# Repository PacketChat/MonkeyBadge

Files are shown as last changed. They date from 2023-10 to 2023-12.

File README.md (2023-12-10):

# Monkey Badge

This repository contains the hardware design files, badge code, and backend
infrastructure code for the HushCon Winter 2023 badge.

## badge

The code for the badge is based on [Micropython][1].  For full documentation
read the datasheet, comments, and commit history.

## api-server

The api-server is the backend gameserver it provides an API
interface for the badge to save state and complete challenges.

You will need a redis server with the json mod, `docker run -d -p 6379:6379
redislabs/redismod` works fine.

This is based on FastAPI and is easily executed with: `cd api-server; python3
api-server`

## scoreboard

Built, with Flask

<!--
vim: ts=2 sw=2 tw=80 syntax=md
!-->

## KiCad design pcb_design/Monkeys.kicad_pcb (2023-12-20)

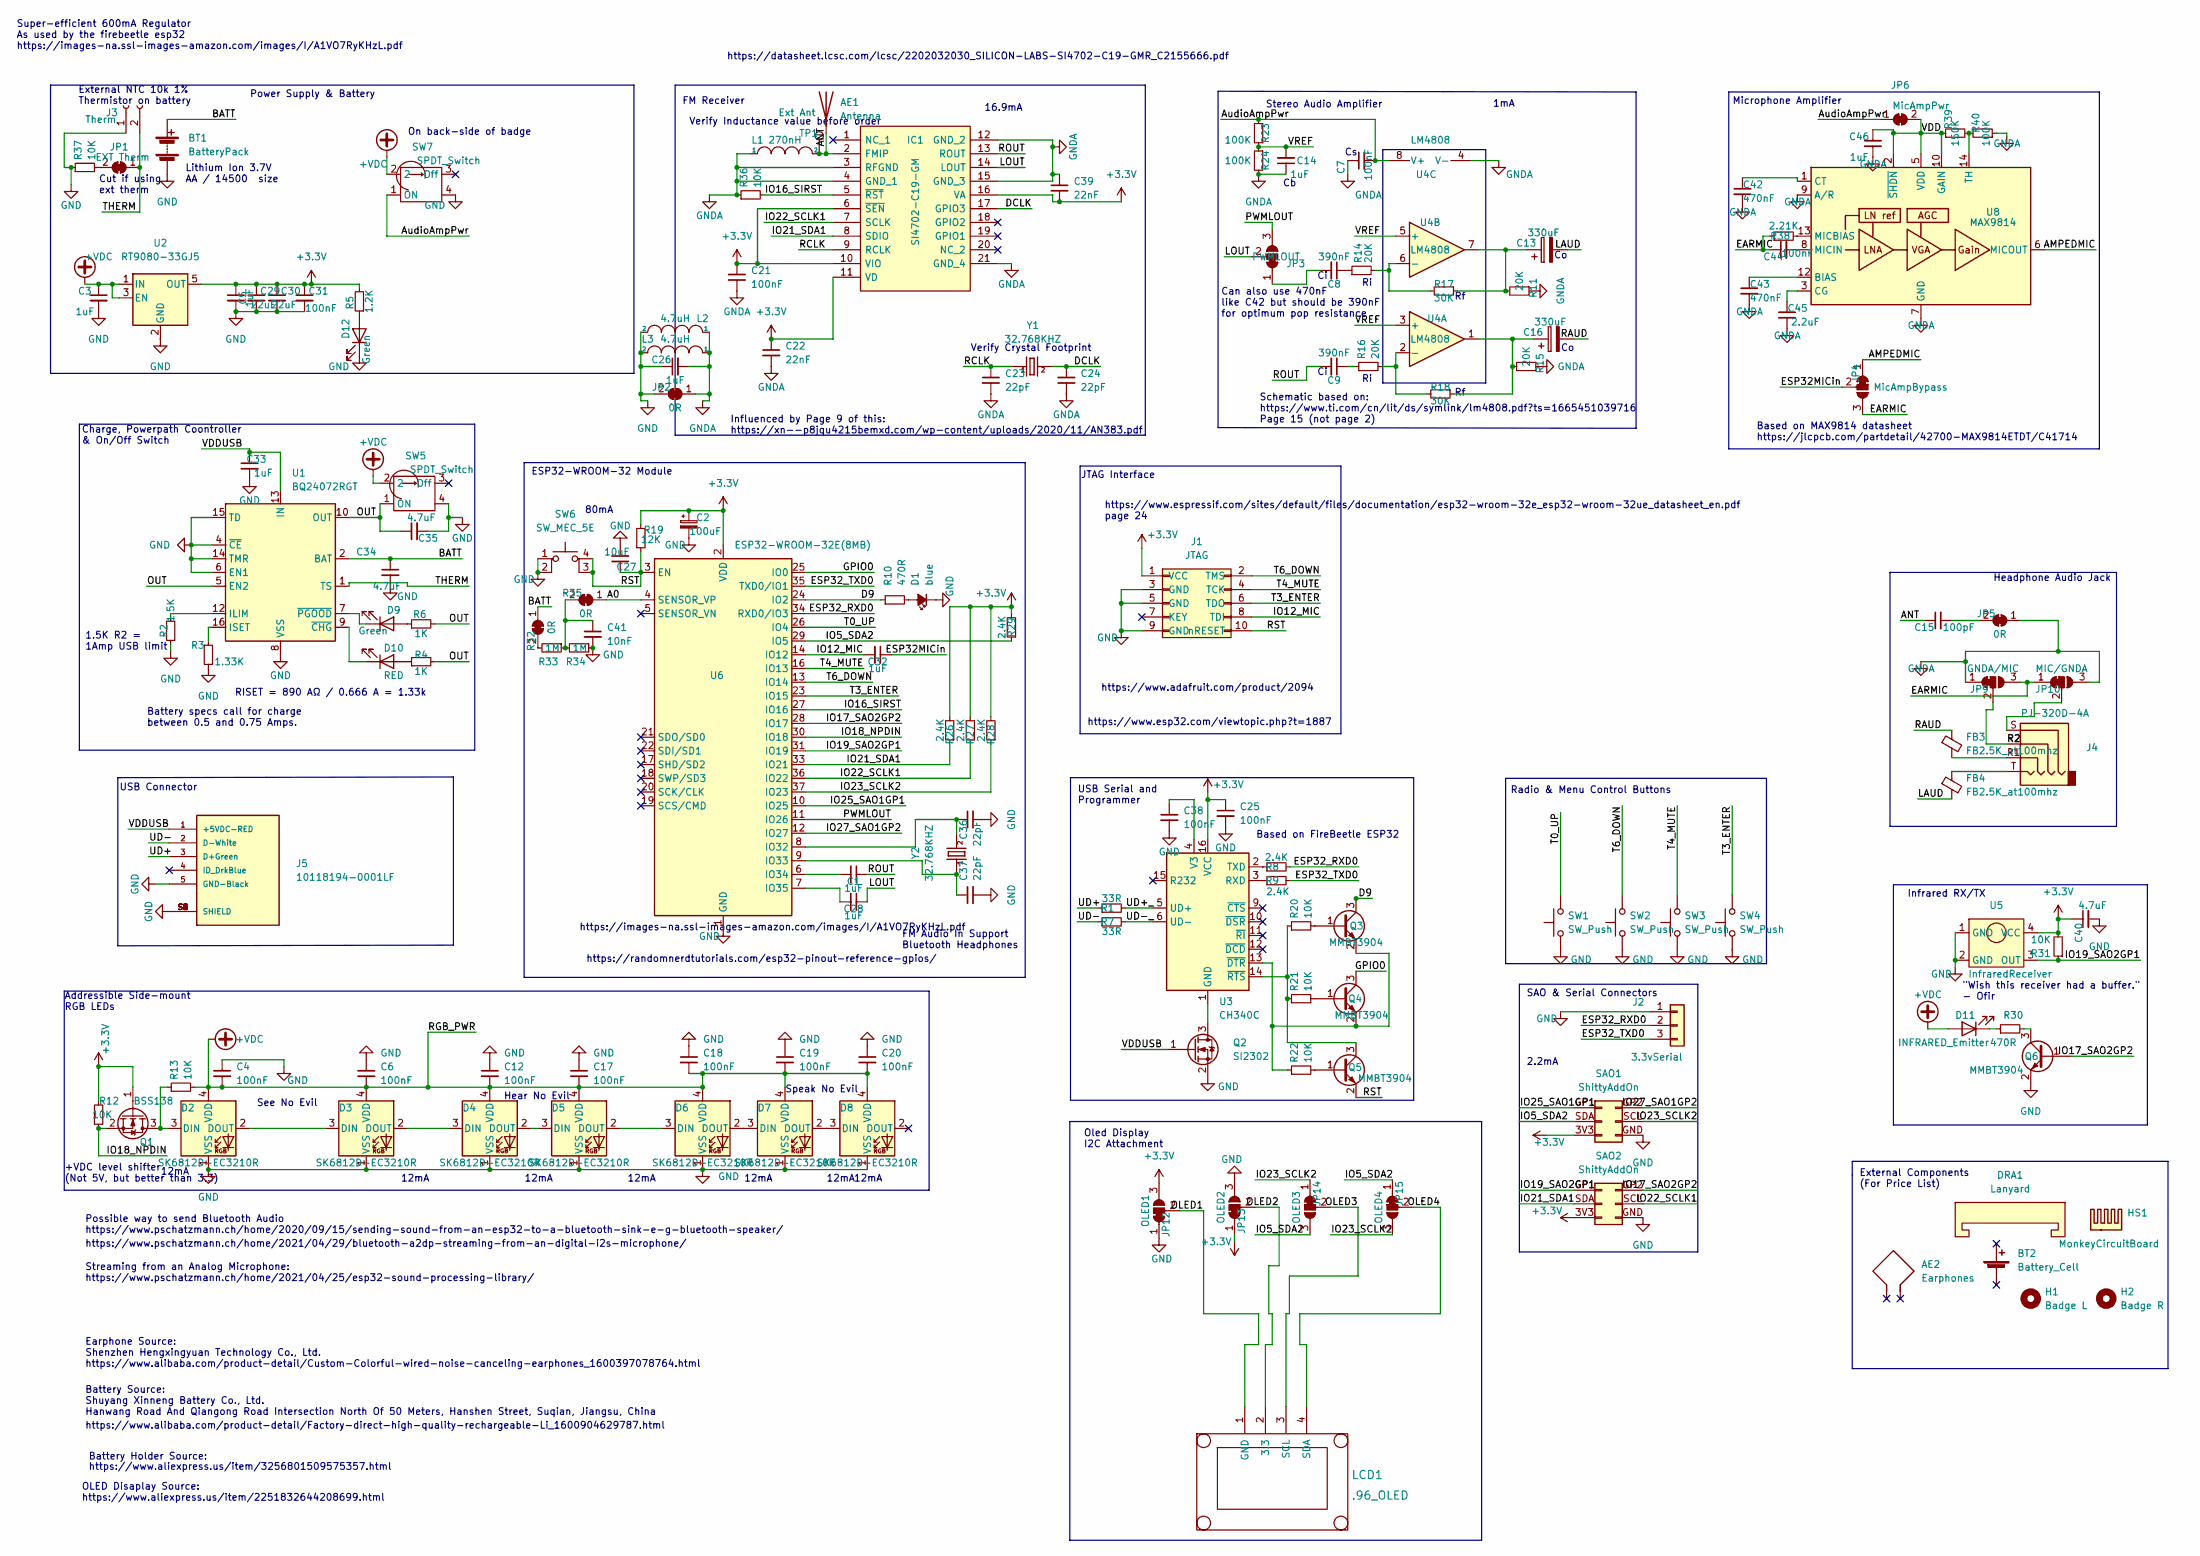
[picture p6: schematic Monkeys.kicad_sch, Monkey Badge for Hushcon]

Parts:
AE1: Antenna; Manufacturer_Part_Number DNP; JLCPCB Part #（optional) DNP
AE2: Earphones; Manufacturer_Part_Number DNP; JLCPCB Part #（optional) DNP
BT1: BatteryPack; 1xAA_NUB; Manufacturer_Part_Number DNP; JLCPCB Part #（optional) DNP
BT2: Battery_Cell; Manufacturer_Part_Number DNP; JLCPCB Part #（optional) DNP
C1, C3, C5, C14, C26, C28, C32, C46: 1uF; C_0402_1005Metric; Manufacturer_Part_Number CC0402KRX5R6BB105; JLCPCB Part #（optional) C106254
C2: 100uF; CP_EIA-6032-20_AVX-F; Manufacturer_Part_Number TAJC107K010RNJ; JLCPCB Part #（optional) C8649
C4, C6, C7, C12, C17, C18, C19, C20, C21, C25, C31, C38, C44: 100nF; C_0402_1005Metric; Manufacturer_Part_Number CL05B104KB54PNC; JLCPCB Part #（optional) C307331
C8, C9: 390nF; C_0402_1005Metric; Manufacturer_Part_Number GRM155R61A394KE15D; JLCPCB Part #（optional) C350937
C13, C16: 330uF; CP_EIA-7343-31_Kemet-D; Manufacturer_Part_Number 6TPC330MA; JLCPCB Part #（optional) C558795
C15: 100pF; C_0402_1005Metric; Manufacturer_Part_Number 0402CG101J500NT; JLCPCB Part #（optional) C1546
C22, C39: 22nF; C_0402_1005Metric; Manufacturer_Part_Number 0402B223K500NT; JLCPCB Part #（optional) C1532
C23, C24, C36, C37: 22pF; C_0402_1005Metric; Manufacturer_Part_Number 0402CG220J500NT; JLCPCB Part #（optional) C1555
C27: 10uF; C_0603_1608Metric; Manufacturer_Part_Number CL10A106KP8NNNC; JLCPCB Part #（optional) C19702
C29, C30: 22uF; C_0805_2012Metric; Manufacturer_Part_Number CL21A226MAQNNNE; JLCPCB Part #（optional) C45783
C33: 1uF; C_0805_2012Metric; Manufacturer_Part_Number CC0805KKX7R8BB105; JLCPCB Part #（optional) C91186
C34, C35, C40: 4.7uF; C_0603_1608Metric; Manufacturer_Part_Number CC0603KRX5R6BB475; JLCPCB Part #（optional) C109456
C41: 10nF; C_0402_1005Metric; Manufacturer_Part_Number CL05B103KB5NNNC; JLCPCB Part #（optional) C15195
C42, C43: 470nF; C_0402_1005Metric; Manufacturer_Part_Number C1005X5R474KDTS; JLCPCB Part #（optional) C147712
C45: 2.2uF; C_0402_1005Metric; Manufacturer_Part_Number LMK105ABJ225MVHF; JLCPCB Part #（optional) C386041
D1: blue; LED_0402_1005Metric; Manufacturer_Part_Number TJ-S1005SW4TGLC6B-A5; JLCPCB Part #（optional) C273603
D2, D3, D4, D5, D6, D7, D8: SK6812D-EC3210R; Manufacturer_Part_Number SK6812D-EC3210R; JLCPCB Part #（optional) C2890041
D9, D12: Green; LED_0805_2012Metric; Manufacturer_Part_Number 17-215SYGC/S530-E2/TR8; JLCPCB Part #（optional) C282125
D10: RED; LED_0603_1608Metric; Manufacturer_Part_Number KT-0603R; JLCPCB Part #（optional) C2286
D11: INFRARED_Emitter; LED_1206_3216Metric; Manufacturer_Part_Number MHT153IRCT; JLCPCB Part #（optional) C2764887
DRA1: Lanyard; DNP; Manufacturer_Part_Number DNP; JLCPCB Part #（optional) DNP
FB3, FB4: FB2.5K_at100mhz; C_0603_1608Metric; Manufacturer_Part_Number SZ1608K252CTF; JLCPCB Part #（optional) C316340
H1: Badge L; MountingHole_4.5mm; Manufacturer_Part_Number DNP; JLCPCB Part #（optional) DNP
H2: Badge R; MountingHole_4.5mm; Manufacturer_Part_Number DNP; JLCPCB Part #（optional) DNP
HS1: MonkeyCircuitBoard; DNP; Manufacturer_Part_Number DNP; JLCPCB Part #（optional) DNP
IC1: SI4702-C19-GM; SI4702C19GM; Manufacturer_Part_Number SI4702-C19-GM; JLCPCB Part #（optional) C2155666
J1: JTAG; PinHeader_2x05_P1.27mm_Vertical; Manufacturer_Part_Number DNP; JLCPCB Part #（optional) DNP
J2: 3.3vSerial; PinSocket_1x03_P2.54mm_Vertical; Manufacturer_Part_Number DNP; JLCPCB Part #（optional) DNP
J3: Therm; PinHeader_1x02_P2.54mm_Vertical; Manufacturer_Part_Number DNP; JLCPCB Part #（optional) DNP
J4: PJ-320D-4A; Jack_3.5mm_PJ320D_Horizontal; Manufacturer_Part_Number PJ-320D-4A; JLCPCB Part #（optional) C95562
J5: 10118194-0001LF; AMPHENOL_10118194-0001LF_JT; Manufacturer_Part_Number 10118194-0001LF; JLCPCB Part #（optional) C132563
JP1: EXT Therm; SolderJumper-2_P1.3mm_Bridged_RoundedPad1.0x1.5mm; Manufacturer_Part_Number DNP; JLCPCB Part #（optional) DNP
JP2, JP5: 0R; SolderJumper-2_P1.3mm_Bridged_RoundedPad1.0x1.5mm; Manufacturer_Part_Number DNP; JLCPCB Part #（optional) DNP
JP3: PWMLOUT; SolderJumper-3_P1.3mm_Bridged12_RoundedPad1.0x1.5mm; Manufacturer_Part_Number DNP; JLCPCB Part #（optional) DNP
JP4: MicAmpBypass; SolderJumper-3_P1.3mm_Bridged12_RoundedPad1.0x1.5mm; Manufacturer_Part_Number DNP; JLCPCB Part #（optional) DNP
JP6: MicAmpPwr; SolderJumper-2_P1.3mm_Bridged_RoundedPad1.0x1.5mm
JP9: GNDA/MIC; SolderJumper-3_P1.3mm_Bridged12_RoundedPad1.0x1.5mm; Manufacturer_Part_Number DNP; JLCPCB Part #（optional) DNP
JP10: MIC/GNDA; SolderJumper-3_P1.3mm_Bridged12_RoundedPad1.0x1.5mm; Manufacturer_Part_Number DNP; JLCPCB Part #（optional) DNP
JP12: OLED1; SolderJumper-3_P1.3mm_Bridged12_RoundedPad1.0x1.5mm; Manufacturer_Part_Number DNP; JLCPCB Part #（optional) DNP
JP13: OLED2; SolderJumper-3_P1.3mm_Bridged12_RoundedPad1.0x1.5mm; Manufacturer_Part_Number DNP; JLCPCB Part #（optional) DNP
JP14: OLED3; SolderJumper-3_P1.3mm_Bridged12_RoundedPad1.0x1.5mm; Manufacturer_Part_Number DNP; JLCPCB Part #（optional) DNP
JP15: OLED4; SolderJumper-3_P1.3mm_Bridged12_RoundedPad1.0x1.5mm; Manufacturer_Part_Number DNP; JLCPCB Part #（optional) DNP
L1: 270nH; L_0603_1608Metric_Pad1.05x0.95mm_HandSolder; Manufacturer_Part_Number SCHF160808HR27JT; JLCPCB Part #（optional) C578010
L2, L3: 4.7uH; L_0603_1608Metric_Pad1.05x0.95mm_HandSolder; Manufacturer_Part_Number MLP2012S4R7MT0S1; JLCPCB Part #（optional) C87543
LCD1: .96_OLED; PinHeader_1x04_P2.54mm_Vertical; Manufacturer_Part_Number DNP; JLCPCB Part #（optional) DNP
Q1: BSS138; SOT-323_SC-70; Manufacturer_Part_Number BSS138W-7-F; JLCPCB Part #（optional) C24553
Q2: SI2302; SOT-23; Manufacturer_Part_Number SI2302; JLCPCB Part #（optional) C351399
Q3, Q4, Q5, Q6: MMBT3904; SOT-23; Manufacturer_Part_Number MMBT3904; JLCPCB Part #（optional) C20526
R1, R7: 33R; R_0402_1005Metric; Manufacturer_Part_Number 0402WGF330JTCE; JLCPCB Part #（optional) C25105
R2: 1.5K; R_0805_2012Metric; Manufacturer_Part_Number RC0805FR-071K5L; JLCPCB Part #（optional) C114555
R3: 1.33K; R_0603_1608Metric; Manufacturer_Part_Number RC0603FR-071K33L; JLCPCB Part #（optional) C137778
R4, R6: 1K; R_0805_2012Metric; Manufacturer_Part_Number RC0805JR-071KL; JLCPCB Part #（optional) C100046
R5: 1.2K; R_0805_2012Metric; Manufacturer_Part_Number AR05FTDW1201; JLCPCB Part #（optional) C724883
R8, R9, R26, R27, R28, R29: 2.4K; R_0603_1608Metric; Manufacturer_Part_Number RC0603FR-072K4L; JLCPCB Part #（optional) C114611
R10, R30: 470R; R_0402_1005Metric; Manufacturer_Part_Number 0402WGF4700TCE; JLCPCB Part #（optional) C25117
R11, R14, R15, R16: 20K; R_0402_1005Metric; Manufacturer_Part_Number 0402WGF2002TCE; JLCPCB Part #（optional) C25765
R12, R13, R20, R21, R22, R31, R36, R37: 10K; R_0402_1005Metric; Manufacturer_Part_Number RC0402FR-0710KL; JLCPCB Part #（optional) C60490
R17, R18: 30K; R_0402_1005Metric; Manufacturer_Part_Number RC0402FR-0730KL; JLCPCB Part #（optional) C138008
R19: 12K; R_0402_1005Metric; Manufacturer_Part_Number RC0402FR-0712KL; JLCPCB Part #（optional) C114760
R23, R24, R40: 100K; R_0402_1005Metric; Manufacturer_Part_Number 0402WGF1003TCE; JLCPCB Part #（optional) C25741
R32, R35: 0R; SolderJumper-2_P1.3mm_Bridged_RoundedPad1.0x1.5mm; Manufacturer_Part_Number DNP; JLCPCB Part #（optional) DNP
R33, R34: 1M; R_0402_1005Metric; Manufacturer_Part_Number 0402WGF1004TCE; JLCPCB Part #（optional) C26083
R38: 2.21K; R_0402_1005Metric; Manufacturer_Part_Number NQ02WGF2211TCE; JLCPCB Part #（optional) C270376
R39: 150K; R_0402_1005Metric; Manufacturer_Part_Number AF0402FR-07150KL; JLCPCB Part #（optional) C144033
SAO1, SAO2: ShittyAddOn; ShittyAddOn_Female; Manufacturer_Part_Number DNP; JLCPCB Part #（optional) DNP
SW1, SW2, SW3, SW4: SW_Push; SW_SPST_PTS645; Manufacturer_Part_Number TSA063G50-250; JLCPCB Part #（optional) C294565
SW5, SW7: SPDT_Switch; SPDT Switch MSK12C02-HB; Manufacturer_Part_Number MSK12C02-HB; JLCPCB Part #（optional) C431541
SW6: SW_MEC_5E; Button_metal; Manufacturer_Part_Number TS-1187A-B-A-B; JLCPCB Part #（optional) C318884
TP1: Ext Ant; PinHeader_1x01_P2.54mm_Vertical; Manufacturer_Part_Number DNP; JLCPCB Part #（optional) DNP
U1: BQ24072RGT; VQFN-16-1EP_3x3mm_P0.5mm_EP1.6x1.6mm; Manufacturer_Part_Number BQ24072RGTR; JLCPCB Part #（optional) C140288
U2: RT9080-33GJ5; SOT-23-5; Manufacturer_Part_Number RT9080-33GJ5; JLCPCB Part #（optional) C841192
U3: CH340C; SOIC-16_3.9x9.9mm_P1.27mm; Manufacturer_Part_Number CH340C; JLCPCB Part #（optional) C84681
U4: LM4808; SOIC-8_3.9x4.9mm_P1.27mm; Manufacturer_Part_Number LM4808MX/NOPB; JLCPCB Part #（optional) C141374
U5: InfraredReceiver; IRM-H638T-TR2; Manufacturer_Part_Number IRM-H638T/TR2(DX); JLCPCB Part #（optional) C390031
U6: ESP32-WROOM-32E(8MB); ESP32-WROOM-32; Manufacturer_Part_Number ESP32-WROOM-32E(8MB); JLCPCB Part #（optional) C701342
U8: MAX9814; DFN-14-1EP_3x3mm_P0.4mm_EP1.78x2.35mm; Manufacturer_Part_Number MAX9814ETD+T; JLCPCB Part #（optional) C41714
Y1, Y2: 32.768KHZ; Crystal_SMD_3215-2Pin_3.2x1.5mm; Manufacturer_Part_Number SF32WK32768D31T002; JLCPCB Part #（optional) C271654

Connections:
+3V3: C2.1, C5.1, C21.1, C22.1, C25.1, C29.1, C30.1, C31.1, C39.2, C40.1, IC1.6 (~SEN), IC1.10 (VIO), IC1.11 (VD), IC1.16 (VA), J1.1 (VCC), JP12.3 (B), JP13.1 (A), Q1.1 (G), R5.2, R12.2, R19.2, R26.2, R27.2, R28.2, R29.2, R31.2, SAO1.3V3, SAO2.3V3, U2.5 (OUT), U3.16 (VCC), U5.4 (VCC), U6.2 (VDD)
+VDC: C3.1, C4.2, C6.2, C12.2, C17.2, C18.2, C19.2, C20.2, D2.4 (VDD), D3.4 (VDD), D4.4 (VDD), D5.4 (VDD), D6.4 (VDD), D7.4 (VDD), D8.4 (VDD), D11.2 (A), R13.2, SW5.2, SW7.2, U2.1 (IN), U2.3 (EN)
/A0: R35.1 (A), U6.4 (SENSOR_VP)
/AMPEDMIC: JP4.1 (A), U8.6 (MICOUT)
/ANT: AE1.1, C15.1, IC1.2 (FMIP), L1.2, TP1.1
/AudioAmpPwr: C7.2, JP6.1 (A), R23.1, SW7.1 (ON), U4.8 (V+)
/BATT: BT1.1 (+), C34.1, R32.1 (A), U1.2 (BAT), U1.3 (BAT)
/D9: Q3.3 (C), R10.1, U6.24 (IO2)
/DCLK: C24.1, IC1.17 (GPIO3), Y1.2
/EARMIC: C44.1, JP4.3 (B), JP9.3 (B), JP10.1 (A), R38.1
/ESP32MICin: C32.1, JP4.2 (C)
/ESP32_RXD0: J2.2, R8.2, U6.34 (RXD0/IO3)
/ESP32_TXD0: J2.3, R9.2, U6.35 (TXD0/IO1)
/GPIO0: Q4.3 (C), U6.25 (IO0)
/IO5_SDA2: JP14.3 (B), JP15.1 (A), R29.1, SAO1.SDA, U6.29 (IO5)
/IO12_MIC: C32.2, J1.8 (TDI), U6.14 (IO12)
/IO16_SIRST: IC1.5 (~RST), R36.2, U6.27 (IO16)
/IO17_SAO2GP2: Q6.1 (B), SAO2.GP2 (GPIO2), U6.28 (IO17)
/IO18_NPDIN: Q1.2 (S), R12.1, U6.30 (IO18)
/IO19_SAO2GP1: R31.1, SAO2.GP1 (GPIO1), U5.3 (OUT), U6.31 (IO19)
/IO21_SDA1: IC1.8 (SDIO), R26.1, SAO2.SDA, U6.33 (IO21)
/IO22_SCLK1: IC1.7 (SCLK), R27.1, SAO2.SCL, U6.36 (IO22)
/IO23_SCLK2: JP14.1 (A), JP15.3 (B), R28.1, SAO1.SCL, U6.37 (IO23)
/IO25_SAO1GP1: SAO1.GP1 (GPIO1), U6.10 (IO25)
/IO27_SAO1GP2: SAO1.GP2 (GPIO2), U6.12 (IO27)
/LAUD: C13.2, FB4.2
/LOUT: C28.1, IC1.14 (LOUT), JP3.2 (C)
/OLED1: JP12.2 (C), LCD1.1 (GND)
/OLED2: JP13.2 (C), LCD1.2 (3.3)
/OLED3: JP14.2 (C), LCD1.3 (SCL)
/OLED4: JP15.2 (C), LCD1.4 (SDA)
/OUT: C35.1, R4.2, R6.2, SW5.1 (ON), U1.5 (EN2), U1.10 (OUT), U1.11 (OUT)
/PWMLOUT: JP3.3 (B), U6.11 (IO26)
/R2: J4.R2, JP9.2 (C)
/RAUD: C16.2, FB3.1
/RCLK: C23.1, IC1.9 (RCLK), Y1.1
/ROUT: C1.1, C9.2, IC1.13 (ROUT)
/RST: C27.1, J1.10 (nRESET), Q5.2 (E), R19.1, SW6.3 (K), SW6.4 (A), U6.3 (EN)
/T0_UP: SW1.2, U6.26 (IO4)
/T3_ENTER: J1.6 (TDO), SW4.2, U6.23 (IO15)
/T4_MUTE: J1.4 (TCK), SW3.2, U6.16 (IO13)
/T6_DOWN: J1.2 (TMS), SW2.2, U6.13 (IO14)
/THERM: J3.2, JP1.1 (A), U1.1 (TS)
/UD+: J5.3 (D+Green), R1.1
/UD+_: R1.2, U3.5 (UD+)
/UD-: J5.2 (D-White), R7.1
/UD-_: R7.2, U3.6 (UD-)
/VDD: C46.1, JP6.2 (B), R39.1, U8.2 (~SHDN), U8.5 (VDD), U8.10 (GAIN)
/VDDUSB: C33.1, J5.1 (+5VDC-RED), Q2.1 (G), U1.13 (IN)
/VREF: C14.2, R23.2, R24.1, U4.3 (+), U4.5 (+)
GND: BT1.2 (-), C2.2, C3.2, C4.1, C5.2, C6.1, C12.1, C17.1, C18.1, C19.1, C20.1, C25.2, C26.1, C27.2, C29.2, C30.2, C31.2, C33.2, C34.2, C35.2, C36.2, C37.2, C38.2, C40.2, C41.2, D1.1 (K), D2.1 (VSS), D3.1 (VSS), D4.1 (VSS), D5.1 (VSS), D6.1 (VSS), D7.1 (VSS), D8.1 (VSS), D12.1 (K), J1.3 (GND), J1.5 (GND), J1.9 (GND), J2.1, J3.1, J5.5 (GND-Black), J5.S1 (SHIELD), J5.S2 (SHIELD), J5.S3 (SHIELD), J5.S4 (SHIELD), J5.S5 (SHIELD), J5.S6 (SHIELD), JP2.2 (B), JP12.1 (A), JP13.3 (B), L2.2, L3.2, Q2.2 (S), Q6.2 (E), R2.1, R3.2, R34.1, R37.1, SAO1.GND, SAO2.GND, SW1.1, SW2.1, SW3.1, SW4.1, SW5.4, SW6.1, SW6.2, SW7.4, U1.4 (~CE), U1.6 (EN1), U1.8 (VSS), U1.14 (TMR), U1.15 (TD), U1.17 (VSS), U2.2 (GND), U5.1 (GND), U5.2 (GND), U6.1 (GND), U6.15 (GND), U6.38 (GND), U6.39 (GND)
GNDA: C7.1, C14.1, C21.2, C22.2, C23.2, C24.2, C26.2, C39.1, C42.2, C43.2, C45.2, C46.2, IC1.3 (RFGND), IC1.4 (GND_1), IC1.12 (GND_2), IC1.15 (GND_3), IC1.21 (GND_4), JP2.1 (A), JP5.1 (A), JP9.1 (A), JP10.3 (B), L1.1, L2.1, L3.1, R11.1, R15.1, R24.2, R36.1, R40.1, U4.4 (V-), U8.4 (GND), U8.7 (GND), U8.9 (A/R), U8.11 (GND), U8.15 (GND)
unnamed: C1.2, U6.6 (IO34)
unnamed: C8.1, R14.1
unnamed: C8.2, JP3.1 (A)
unnamed: C9.1, R16.1
unnamed: C13.1, R11.2, R17.1, U4.7
unnamed: C15.2, JP5.2 (B)
unnamed: C16.1, R15.2, R18.1, U4.1
unnamed: C28.2, U6.7 (IO35)
unnamed: C36.1, U6.8 (IO32), Y2.2
unnamed: C37.1, U6.9 (IO33), Y2.1
unnamed: C38.1, U3.4 (V3)
unnamed: C41.1, R33.1, R34.2, R35.2 (B)
unnamed: C42.1, U8.1 (CT)
unnamed: C43.1, U8.12 (BIAS)
unnamed: C44.2, U8.8 (MICIN)
unnamed: C45.1, U8.3 (CG)
unnamed: D1.2 (A), R10.2
unnamed: D2.2 (DOUT), D3.3 (DIN)
unnamed: D2.3 (DIN), Q1.3 (D), R13.1
unnamed: D3.2 (DOUT), D4.3 (DIN)
unnamed: D4.2 (DOUT), D5.3 (DIN)
unnamed: D5.2 (DOUT), D6.3 (DIN)
unnamed: D6.2 (DOUT), D7.3 (DIN)
unnamed: D7.2 (DOUT), D8.3 (DIN)
unnamed: D9.1 (K), U1.7 (~PGOOD)
unnamed: D9.2 (A), R6.1
unnamed: D10.1 (K), U1.9 (~CHG)
unnamed: D10.2 (A), R4.1
unnamed: D11.1 (K), R30.1
unnamed: D12.2 (A), R5.1
unnamed: FB3.2, J4.R1
unnamed: FB4.1, J4.T
unnamed: J4.S, JP10.2 (C)
unnamed: JP1.2 (B), R37.2
unnamed: Q2.3 (D), U3.1 (GND)
unnamed: Q3.1 (B), R20.2
unnamed: Q3.2 (E), Q4.2 (E), R22.1, U3.13 (~DTR)
unnamed: Q4.1 (B), R21.2
unnamed: Q5.1 (B), R22.2
unnamed: Q5.3 (C), R20.1, R21.1, U3.14 (~RTS)
unnamed: Q6.3 (C), R30.2
unnamed: R2.2, U1.12 (ILIM)
unnamed: R3.1, U1.16 (ISET)
unnamed: R8.1, U3.2 (TXD)
unnamed: R9.1, U3.3 (RXD)
unnamed: R14.2, R17.2, U4.6 (-)
unnamed: R16.2, R18.2, U4.2 (-)
unnamed: R32.2 (B), R33.2
unnamed: R38.2, U8.13 (MICBIAS)
unnamed: R39.2, R40.2, U8.14 (TH)

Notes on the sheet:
See No Evil
Can also use 470nF like C42 but should be 390nF for optimum pop resistance
https://www.alibaba.com/product-detail/Factory-direct-high-quality-rechargeable-Li_1600904629787.html
Addressible Side-mount RGB LEDs
Battery specs call for charge between 0.5 and 0.75 Amps.
https://www.aliexpress.us/item/3256801509575357.html
12mA
Speak No Evil
https://datasheet.lcsc.com/lcsc/2202032030_SILICON-LABS-SI4702-C19-GMR_C2155666.pdf
On back-side of badge
"Wish this receiver had a buffer." - Ofir
Radio & Menu Control Buttons
https://randomnerdtutorials.com/esp32-pinout-reference-gpios/
Verify Inductance value before order
https://www.esp32.com/viewtopic.php?t=1887
1.5K R2 = 1Amp USB limit
https://www.pschatzmann.ch/home/2021/04/29/bluetooth-a2dp-streaming-from-an-digital-i2s-microphone/
+VDC level shifter (Not 5V, but better than 3.3)
Streaming from an Analog Microphone: https://www.pschatzmann.ch/home/2021/04/25/esp32-sound-processing-library/
Earphone Source: Shenzhen Hengxingyuan Technology Co., Ltd. https://www.alibaba.com/product-detail/Custom-Colorful-wired-noise-canceling-earphones_1600397078764.html
Based on FireBeetle ESP32
https://www.espressif.com/sites/default/files/documentation/esp32-wroom-32e_esp32-wroom-32ue_datasheet_en.pdf page 24
Cut if using ext therm
https://www.adafruit.com/product/2094
Stereo Audio Amplifier
Oled Display I2C Attachment
OLED Disaplay Source: https://www.aliexpress.us/item/2251832644208699.html
External Components (For Price List)
Headphone Audio Jack
Battery Source: Shuyang Xinneng Battery Co., Ltd. Hanwang Road And Qiangong Road Intersection North Of 50 Meters, Hanshen Street, Suqian, Jiangsu, China
https://images-na.ssl-images-amazon.com/images/I/A1VO7RyKHzL.pdf
SAO & Serial Connectors
Based on MAX9814 datasheet https://jlcpcb.com/partdetail/42700-MAX9814ETDT/C41714
Battery Holder Source:
RISET = 890 AΩ / 0.666 A = 1.33k
FM Audio In Support Bluetooth Headphones
Power Supply & Battery
2.2mA
Possible way to send Bluetooth Audio https://www.pschatzmann.ch/home/2020/09/15/sending-sound-from-an-esp32-to-a-bluetooth-sink-e-g-bluetooth-speaker/
Infrared RX/TX

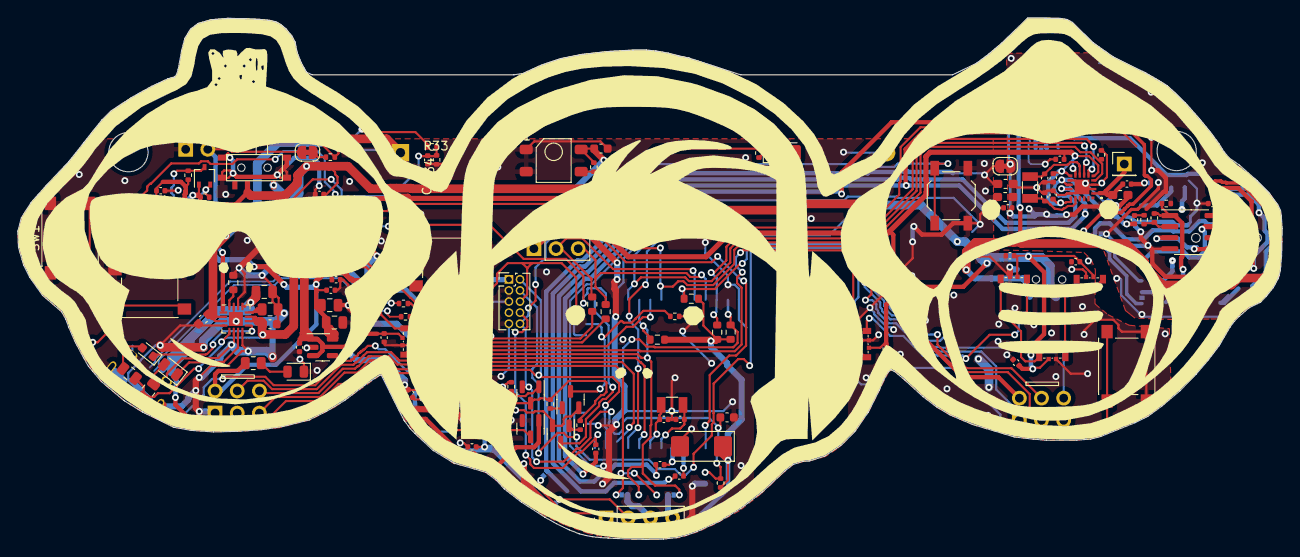
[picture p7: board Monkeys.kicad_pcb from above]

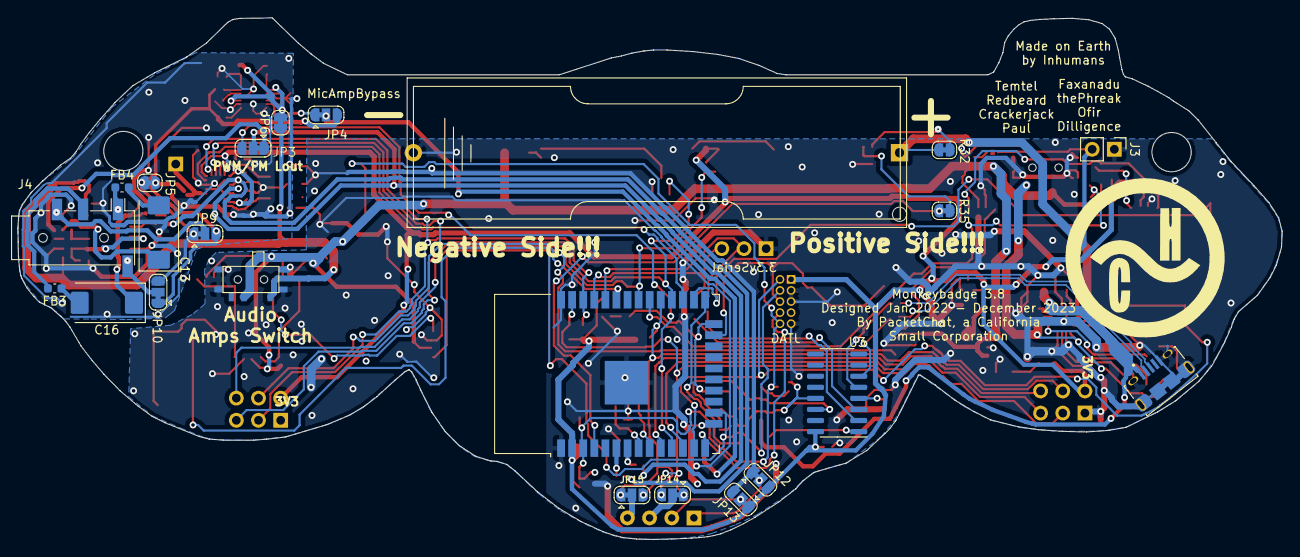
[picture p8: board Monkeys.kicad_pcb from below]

Board: 2 copper layers, 144.9 x 59.8 mm, 147 parts (23 on the bottom side), 102 nets.

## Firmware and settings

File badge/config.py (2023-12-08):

"""configuration settings"""
from collections import namedtuple
from esp32 import NVS

nvs = NVS("monkeybadge")
WIFI_SSID = "HushCon"
WIFI_PASSWORD = "ThreeAmigos"
API_SERVER = "https://update.kafka.tel/api"


def setNVS(key, value):
    nvs.set_blob(key, value)
    nvs.commit()


def getNVS(key, size):
    b = bytearray(size)
    nvs.get_blob(key, b)
    value = b.decode("utf-8").strip("\x00")
    del b
    return value


def eraseNVS(key):
    try:
        nvs.erase_key(key)
    except Exception:
        # TODO: if we don't mask this users will likely see they can modify the value "API_SERVER"
        # pass
        print("Unable to erase key {}".format(key))


# Wifi Config
try:
    WIFI_SSID = getNVS("WIFI_SSID", 32)
except Exception:
    pass

try:
    WIFI_PASSWORD = getNVS("WIFI_PASSWORD", 63)
except Exception:
    pass

try:
    API_SERVER = getNVS("API_SERVER", 255)
except Exception:
    pass

RESET_URL = "https://update.kafka.tel/firmware/reset.json"
UPDATE_URL = "https://update.kafka.tel/firmware/update.json"

# badge config
REG_KEY = "7bc78281-2036-41b2-8d98-fc23ec504e9a"
MONKEY_PERIOD = 5000
CHECKIN_PERIOD = 60000
BUTTON_PINS = [4, 14, 15, 13]
BUTTON_PIN_DESCRIPTIONS = [
    "left up",
    "left down",
    "center",
    "right",
]

# OLED screen Config
OLED_HEIGHT = 64  # height (int): Height of the display in pixels.
OLED_WIDTH = 128  # width (int): Width of the display in pixels.
OLED_SDA_PIN = 5  # sda_pin (int): Pin number for the SDA (data) line of the I2C bus.
OLED_SCL_PIN = 23  # scl_pin (int): Pin number for the SCL (clock) line of the I2C bus.

# IR Pins (also double as right SAO GPIO pins)
IR_RX_PIN = 19  # SAO2 GPIO1
IR_TX_PIN = 17  # SAO2 GPIO2

# SAO1 Pins
SAO1_GPIO1 = 25
SAO1_GPIO2 = 27


# IR Definitions Follow
# examples (addr, data):
# DISCOVER: (0x000a, 0x01)
# HERE: (0x000b, 0x02)  <--- add to last seen
# INIT_PAIR: (0x000a, 0x03)
# RESP_PAIR: (0x000b, 0x04, 0x00, 0x0a) <--- responding to 0x000a
# ACK_RESP: (0x000a, 0x05, 0x00, 0x0b) <--- confirming 0x000b response
# EMOTE: (0x000a, 0x06, 0x01, 0x00, 0x0b) <--- a wants be to show emote 0x01 (lol)
# EMOTE: (0x000b, 0x06, 0x02, 0xff, 0xff) <--- b wants all badges in the vicinity
#                                              to show emote 0x02 (lmao)
# MONKEY: (0xffff, 0x07, 0xaa, 0xaa) <--- monkey ffff secret pass aaaa
# HIDDEN_OBJECT: (0xeeee, 0x08, 0xbb, 0xbb) <---- hidden object eeee with
#                                                 secret pass bbbb
Opcode = namedtuple("Opcode", ["code", "additional_bytes"])
IR_OPCODES = {
    "DISCOVER": Opcode(1, 0),
    "HERE": Opcode(2, 0),
    "INIT_PAIR": Opcode(3, 0),
    "RESP_PAIR": Opcode(4, 2),
    "ACK_RESP": Opcode(5, 2),
    "EMOTE": Opcode(6, 1),
    "MONKEY": Opcode(7, 0),
    "HIDDEN_OBJECT": Opcode(8, 0),
}
REV_IR_OPCODES = {val.code: key for key, val in IR_OPCODES.items()}

EMOTES = {
    (1 << 4) + 1: "lol",
    (1 << 4) + 2: "lmao",
    (1 << 4) + 3: "gtfo",
    (1 << 4) + 4: "rtfm",
    (1 << 4) + 5: "tldr",
    (1 << 4) + 6: "RNGesus",
    (1 << 4) + 7: "rofl",
    (1 << 4) + 8: "brb",
    (1 << 4) + 9: "stfu",
    (1 << 4) + 10: "wtf",
    (1 << 4) + 11: "ffs",
    (1 << 4) + 12: "smh",
    (1 << 4) + 13: "smdh",
    (1 << 4) + 14: "ifykyk",
    (1 << 4) + 15: "omg",
    (1 << 4) + 16: "uwu",
    (1 << 4) + 17: "skill issue",
    (1 << 4) + 18: "pspsps",
}


IR_TX_DELAY = 175  # delay between tx pulses in ms
# messages received after this much delay (in ms) become a new message
IR_RX_MAX_DELAY = 250

CLEAN_BADGE_AFTER = 120000  # 120s

# Battery monitor:
FULLY_CHARGED_ADC_VALUE = 2404
DEPLETED_ADC_VALUE = 1500
MAX_VOLTAGE = 2.4
ADC_PIN = 36
MIN_POWER_READING = 5

# Radio
LOCKED_FREQ = 107.5

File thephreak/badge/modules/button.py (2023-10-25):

import machine
import uasyncio as asyncio
import utime

class ButtonHandler:
    def __init__(self, button_pins, debounce_time=300):
        self.button_pins = button_pins
        self.buttons = [machine.Pin(pin, machine.Pin.IN, machine.Pin.PULL_UP) for pin in button_pins]
        self.last_pressed = [0] * len(button_pins)
        self.debounce_time = debounce_time

        for idx, button in enumerate(self.buttons):
            button.irq(trigger=machine.Pin.IRQ_FALLING, handler=lambda p, idx=idx: self._generic_callback(idx))

    def _generic_callback(self, button_idx):
        current_time = utime.ticks_ms()
        if utime.ticks_diff(current_time, self.last_pressed[button_idx]) > self.debounce_time:
            self.last_pressed[button_idx] = current_time
            print(f"Button press detected on pin: {self.button_pins[button_idx]}")

    async def check_buttons(self):
        while True:
            for idx, button in enumerate(self.buttons):
                if button.value() == 0:
                    self._generic_callback(idx)
            await asyncio.sleep(0.1)  # non-blocking wait for 100ms

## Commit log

2023-09-16 docs: Add basic directions for RSC
    This is designed to be a basic dumping ground for "not ready for prime
    time" code throughout the Packet Chat organization.
2023-09-25 Checking in current send and receive code.
2023-09-26 monkeybadge: new HAL with IR support
    This introduces a new HAL for testing.
    On instantiation it loads the NEC 16 protocol using an interrupt
    mechanism on the ESP32 and the underlying RMT device. It does this in a
    "micropython" way without making any changes to how MicroPython works
    itself. I may consider this for adoption into BadgePython in the
    future.
    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
2023-09-26 Adding IR ASCII sending prototype.
2023-09-26 Revert "Adding IR ASCII sending prototype."
    This reverts commit b673e533c030224b9b12484ca0eb11919e8fd5b3.
    [fax_ir_simple_receive.py, fax_ir_simple_send.py]
2023-10-13 initial api server
    [pyvenv.cfg]
2023-10-25 broke up program into modules, created async execution cycle for main loop
    [config.py]
2023-10-26 buttons, menu, working
2023-11-01 functional Menu system, LEDs and more
2023-11-12 initial commit cleanup
    [pyvenv.cfg]
2023-11-14 bug: VirtualEnvs are not portable across systems
    A VirtualEnv should be created outside of source control to avoid host
    specific values and (occasinally) instruction set architecture specific
    code. In this case the VirtualEnv had a number of hard coded values
    corresponding to a single users MacOS host.
2023-11-19 expand ir module and fix some small issues
    [config.py]
2023-11-22 feature: Add OTA update capability
    This adds some over the air update functionality along with the
    abstraction of some configuration values into non-volatile storage.
    In addition, WiFi performs a hardware reset on connect to work around an
    Espressif errata and now displays the name of the WiFi network being
    connected.
    [boot.py, config.py]
2023-11-22 hw: MicroPython board definition files.
    These files are used to compile MicroPython with the specific
    configuration for the Hushcon West 2023 "MonkeyBadge".
    Within MicroPython there are two primary environment variables which can
    be used to configure the project:
    - `MICROPYTHON_BOARD`
    - `MICROPYTHON_BOARD_DIR`
    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
    [monkeybadge-partitions.csv]
2023-11-22 chore: Adding a build action for the badge firmware
    This is a basic scaffolding of the use of GitHub actions to monitor the
    repository for changes to the badge firmware and or the board
    definition.
    As of right now there are five core actions:
    - Check out the repository
    - Check out MicroPython
    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
2023-11-29 Feature: Adding a self-hosted runner
    Adding a self-hosting runner for the purpose of the local build system.
    We're not worried with overloading the system, so (for now) taking off
    some of the restrictions and allowing any changes to the GitHub
    workflows to trigger a build.
    Previously using the basic GitHub action was taking over five minutes to
    complete. I'm hoping this gets us under 30 seconds. :fingers_crossed:
    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
2023-11-29 bug: SI470X method rename (set_volume)
    In a prior update to the MonkeyBadge class the method set_volume was
    renamed to setVolume(). This was discovered when performing a manual
    audit of the code base, as can be seen below:
    ```
    >>> b.radio.changeVolume(12)
    Traceback (most recent call last):
    File "<stdin>", line 1, in <module>
    File "library/radio.py", line 551, in changeVolume
    AttributeError: 'SI470X' object has no attribute 'set_volume'
    ```
    This commit both resolves the naming issue for the function of the class
    as well as removing an extraneous carriage return at the end of the
    file. As such, we no longer need the "Tuning" property on the class nor
    the missing `tune()` function as ca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
2023-11-30 introduces micropython schedule function removing unsued machine library
    cleaning up button callback logic.
2023-11-30 feature: refactor led library
    removed the demo function - it's not used
    run led playback via asyncio
2023-12-01 bug: Remove bare except calls
    The `pydocstyle` linter defines `E722` for the use of a bare `except`
    statement. As per the `ruff` linter's documentation:
    > # bare-except (E722)
    >
    > Derived from the pycodestyle linter.
    >
    > ## What it does
    >
    > Checks for bare except catches in try-except statements.
    >
    > ## Why is this bad?
    >
    > A bare except catches BaseException which includes KeyboardInterrupt,
    > SystemExit, Exception, and others. Catching BaseException can make it
    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
    [config.py]
2023-12-02 chore: fixing badge exec loop issues
    [config.py]
2023-12-02 BUG: fixed button 3 pulling up main menu
    button 3 was causing the main menu to display
    during the konami game. since this button does
    nothing I gave it the same function as button 4
2023-12-02 chore: formatting, and I added back the print_lines for OTA
    we removed print_lines function in favor of the framebuffer,
    we need something simple for OTA update message, so I added
    it back in.
2023-12-02 chore: formatting + fixing ota urls in monkeybadge
    boot.py - had a spelling error
    db.py - formatting and ignore for linter
    gameclient.py - removed unused modules and changed None to return None.
    monkeybadge.py - removed unused modules, formatting.
    [boot.py]
2023-12-02 fix some linter errors (#43)
    * fix some linter errors
    * remove pin reference from tx init
2023-12-02 nit: Cleaning up the routines in the leds class (#44)
    Python linter failed with the following errors:
    > Error: badge/library/leds.py:712:9: F841 Local variable `delay_per_group` is assigned to but never used
    > Error: badge/library/leds.py:811:9: F841 Local variable `end_time` is assigned to but never used
    This code resolves these errors.
2023-12-02 feature: implemented IR pairing
    monkeybadge.py
    - added in missing menu items for Init Pair / Pair mode.
    - renamed init pair / pair mode to "Match send / Match recv"
    - wired in friendrequest to op code INIT_PAIR
    gameclient.py
    - added new headers containing:
    -- `content-type: application/json`
    -- `User-Agent: MonkeyBadge/{version}`
    - added friendrequest function to make the call to the api-server
    to register a match with another badge.
2023-12-02 feature: Battery Meter (#48)
    Adding a class for measuring the battery life. The `Meter` class
    contains an `info()` method that calculates the battery life based on the
    measurement returned of the ADC reading. The math is a little weird
    because I had to average it on various batteries and there's a voltage
    divider that gives me only 2.4V to measure.
    Changes:
    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
2023-12-02 chore: Clean up Ruff linting / formatting (#47)
    This adds the `.ruff_cache` directory to `.gitignore`, adds the
    api-server to the scanned code paths, and disables Ruff formatting
    around the I2C status table for the Si470x radio.
2023-12-03 feature: OLED brightness controls (#52)
    * feature: OLED brightness controls
    Adding a menu item with a helper function to set the OLED brightness
    globally. These settings are contrast values ranging from 1-255. Three
    settings exist for setting the contrast to low, medium and high which
    set it to 1, 80 and 200 respectively.
    I also added a default contrast setting of 1, so that when the badge
    boots the brightness starts at the lowest possible value to preserve
    battery.
    The contrast mode is set from the menu via a lambda function so that it
    doesn't set the contrast when the menu is activated. It calls a helper
    function that has a parmeter called `mode` that you pass. The `mode`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
2023-12-03 Add threading to LED calls (#54)
    * Add threading to LED calls
    * Add a function to create a thread that will run LEDs async
    * Up the stack size before creating the thread so that the
    thread doesn't cause issues
    * Implement the code in the lightshow menu
    * Reformat with ruff
2023-12-03 fix: Removing unused menu items. (#57)
    Removed the LED Brightness global setting menu since we're not setting
    that. Also removed the Debounce menu.
    Tested on the badge with the latest firmware, good to go.
2023-12-04 feature: implementing challenge2 / challenge3 (#60)
    - added monkeysee code to validate each monkey and update the gamestate
    - added hiddenobject code to validate each object and update the gamestate
    both of these will also progress the game state
    - changed uuid to irid for uberbadges
    - gameclient.py - disabled a print statement
    - config.py - radio locking freq defined
    - monkeybadge.py
    -- added checks for changes to the incoming gamestate in save_gamestate()
    this will alert the player that something happened.
    moved state check and messages to load_gamestate
    fixed some spelling issues
    changed the uberbadge to int
    [boot.py, config.py]
2023-12-04 fix import error in boot.py (#64)
    [boot.py]
2023-12-05 Add hardware history (#66)
    * hardware: Adding initial hardware
    This is the hardware for the "MonkeyBadge", an as yet to be released
    "BadgeLife" device. This device features an Si4702 FM radio reciever,
    an SSD1306 OLED screen, infrared TX/RX, to "standardized add-on" (SAO)
    ports, and other goodies.
    This spin of the hardware went to initial manufacturing with the gerbers
    provided on October 22nd, 2022.
    * hardware: Badge revision v2.2
    After some initial testing we came up with a number of errata as noted
    here. These changes have been implemented:
    - Need to replace the infrared LED emitter with one that is
    front-facing, and doesn’t require hand-soldering.
    - Make a tru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
    [Monkeys-B_Cu.gbr, Monkeys-B_Fab.gbr, Monkeys-B_Mask.gbr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]
2023-12-05 feature: Add light shows (#67)
    * feature: Random list of 5 lightshows for menu
    This doesn't work yet, checking in to see if someone can review and tell
    me if I'm going in the right direction.
    Thanks.
    * feature: Added all LED light shows
    Added a dictionary `lightshow_dict` to `library/leds.py` to store a key
    value pair for each light show function and a friendly name. Then I
    initialized an empty list `selected_lightshows` to store 5 random
    light shows to be displayed in the menu. Added a helper function
    `selected_lightshows()` that returns the list. I also refactored any
    light show that took parameters and internalized all the values within
    each light show method. The only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
    [config.py]
2023-12-05 Add Monkey Mode Client (#65)
    * Add Monkey Mode Client
    * add state to put badge into monkey mode
    * monkey mode broadcasts a monkey_id every 5s (configurable)
    * adds logic to turn on monkey mode and turn it off
    * adds an api in ir.py to broadcast a monkey_id
    * Swap low:high variance check for high:low variance check
    * ruff monkeybadge.py
    * add wifi enable on init
    [config.py]
2023-12-05 Add emote functionality (#68)
    * Add emote functionality
    * added list of emotes in config
    * fix send_emote function in ir lib to remove dst
    * add emote submenu in social menu
    * populate emote submenu with emotes from config
    * add EMOTE ir packet handler in infrared_check
    * Add sender info to timed message, auto-format
    * auto-format through ruff
    * add sender information to timed message on emote
    * Minor improvements
    * change emote range so that emote code cannot be mistaken for opcodes
    * change timed message to include sender
    * ruff formatting
    [config.py]
2023-12-05 feature: ir pairing, now with more data! (#72)
    - changed the matches format from irid:uuid
    - now when saving a friend match, both players are updated!
    - updates to pairing state
    - added friend menu items
    - fixed bug with current challenge
    - only display challenge completion on payload change (instead of loading from DB)
2023-12-05 bug: fixed scoreboard failing to load (#73)
    there are multiple types of keys in redis now,
    I built a simple function that validates the key
    is a proper uuid (in this case a hyphen deliminated mac addr)
2023-12-05 bug: if a badge does checkin and the server has lost the data, the badge is stuck (#74)
    bug: if a badge is trying to checkin and the server has lost the data, the badge is SOL
    In the situation where a badge's DB key is lost, the badge is unusable.
    to fix this, I added a check for a 404 from checkin on the apiserver,
    if the badge receives a 404 - that means the badge doesnt exist.
    the badge will try to re-register with the current API token. If the token exists in the api-keys
    table, it's ignored, otherwise it will be added as well.
    I also changed the initial last_checkin value to -61000 to ensure we checkin on the first event loop.
    forgot to remove an err
2023-12-07 bug: Introduced a better battery meter (#76)
    * bug: Introduced a better battery meter
    Ripped out the old battery logic. This Meter class still returns a
    formatted percentage, but it's way more accurate.
    I take the max measured adc value of 2404 with my best battery and
    call that 100%. If the adc value is greater than or equal to 2404, the
    percentage gets set to 100%, if it's less than or equal to 1500, it
    sets it to 0%. Anything in between is broken down into a percentage and
    returned.
    A power bar and a percentage is still printed to the console.
    * fix: Ran ruff
    Just ran ruff check and format.
2023-12-07 feature: Battery charge warning message (#79)
    * feature: Battery charge warning message
    Added a small power check in the main controller. I figured this is
    where you should put this since it's so important.
    The power level is first stored, then sliced and the whole integer is
    used as the threshold, currently set to `5`. The power meter's range is
    definitely safe enough to go lower, but just in case some batteries
    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
2023-12-08 bug: Display message about update on boot (#81)
    To avoid any confusion about wondering what the badge is doing we are
    displaying a message about performing an over the air update to the
    SSD1306 display when occurring.
    [boot.py]
2023-12-08 feature: radio station locking for challenge2. (#82)
    bug fixes / superficial changes:
    - config.py - comment
    - library/battery.py - removed print statement
    - library/radio.py - changed getFreq return to int instead of string.
    feature work:
    - library/monkeybadge.py - modified seekup/down to check if station is
    locked, and will prevent tuning to the locked station
    - adjusted how loadstate sets challenge2 specific settings
    - loadstate in checkin should ALWAYS load state from db, not payload.
    this was causing the badge to lock the display with challenge messages.
    - fixed exception call for checkin to still set the last_checkin variable
    so that when somethign crashes, the badge isn't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
    [config.py]
2023-12-08 feature: added a CLI to the badge (#84)
    feature: badge_cli
    commented out gameclient print statements
    changed monkeybadge print statement to logger
    badge_cli adds several features to interact with the badge.
    recovery of API tokens
    factory reset
    fixing linting error
2023-12-08 bug: Set BlockdevWriter.writer to None (#83)
    * bug: Set BlockdevWriter.writer to None
    Since we know that we don't want to perform any write to the flash in
    the event of a SHA match, explicitly set the `.writer` property to None.
    * bug: Flash menu options not returning to menu
    This resolves a bug where the `flash_badge()` failed to return to to the
    menu leading to a crash.
    * nit: Remove spurious comment
    This removes a TODO comment because the work has been completed.
    [boot.py]
2023-12-08 feature: made the challenge2/3 requests queued. (#86)
    * feature: made the challenge2/3 requests queued.
    In case wifi is not working at the time the challenge is completed
    the call will queue.
    monkeyseerequest and hiddenobjectrequest.
    * feature: added badge handle display via about menu
    realized there was no way to see what my handle is on the badge,
    displaying it on the About menu.
2023-12-20 Post Hushcon hardware fixes: - Removed the bad 5v boost converter, inductor and capacitor that resulted in a back-side hardware bypass hack at Hushcon Seattle. - Replaced the over-voltage VDC with +3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
    [Monkeys.kicad_pcb, Monkeys.kicad_sch]

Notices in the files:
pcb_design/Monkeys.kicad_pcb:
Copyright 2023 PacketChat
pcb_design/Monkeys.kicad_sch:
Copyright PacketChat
